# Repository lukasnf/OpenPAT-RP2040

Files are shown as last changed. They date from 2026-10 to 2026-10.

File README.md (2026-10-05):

# OpenPAT-RP2040

> **⚠️ SAFETY DISCLAIMER:** This project is for educational and preliminary diagnostic purposes only. While it tests electrical safety parameters, it is **not** a certified Portable Appliance Tester (PAT). It does not replace legally required safety tests conducted with calibrated and certified equipment. Always assume appliances are dangerous until proven otherwise.

**OpenPAT-RP2040** is a low-voltage Portable Appliance Tester based on the RP2040 microcontroller. It is designed to safely measure Protective Earth (PE) continuity at standard test currents (200mA) and verify Phase-to-Neutral (L-N) resistance on **unpowered** appliances. 

Operating completely without high measurement voltages, this design allows for safe preliminary testing of appliances. 

> **Note:** This project is currently under active development. The schematics and PCB layout have been designed using KiCad and manufactured via JLCPCB.

---

## 🛠 Hardware Architecture

The measurement circuitry is designed around the RP2040 and relies on a dedicated analog frontend for precise, low-voltage readings. Based on the schematic, the core components and sub-circuits include:

* **Microcontroller:** RP2040
* **Analog-to-Digital Converter (ADC):** ADS1115 connected via I2C (`I2C_SCL`, `I2C_SDA`) to read the measurement nodes (`PE_TEST`, `PE_TEST_RE`, `L_T`, `N_T`).
* **PE Test Current Source:** A constant current source generating approximately 200mA. This is achieved using an LM317 linear regulator (U1) combined with a 6.2Ω / 1W resistor (R1).
* **PE Continuity Measurement:** Employs a **4-wire (Kelvin) measurement method** to accurately determine resistance by eliminating the voltage drop across the test leads. This is implemented using separate connections for force (`PE_FORCE_IN`, `PE_OUT1`) and sense (`PE_SENSE_1`, which connects to the protected `PE_TEST_RE` node).
* **L-N Resistance Measurement:** Controlled via RP2040 GPIOs. An NMOS transistor (Q1, controlled by GP26) and a switched pull-up (via GP27 and a 1kΩ resistor) are used to configure the circuit to measure the resistance between the Phase and Neutral test points via the L/N_TEST1 connector.
* **Input Protection:** All sensitive analog measurement lines are protected against transients. The circuit uses 10kΩ series resistors (R2, R3, R4, R5) and BAT54S dual Schottky diodes (D1, D2, D3, D4) to safely clamp the ADC inputs to the 3.3V rail and Ground.

## 📂 Repository Contents
Bildschirmfoto 2026-10-05 um 15 35 09



...

## 📄 License

This repository contains both hardware design files and software source code, which are licensed differently:

* **Hardware:** All hardware design files (schematics, PCB layouts) are released under the [CERN Open Hardware Licence Version 2 - Strongly Reciprocal (CERN-OHL-S v2)](LICENSE).
* **Software:** All source code is released under the [MIT License](LICENSE-MIT).

This README was drafted with AI assistance. All technical information has been manually verified by the author.

Lukas F.

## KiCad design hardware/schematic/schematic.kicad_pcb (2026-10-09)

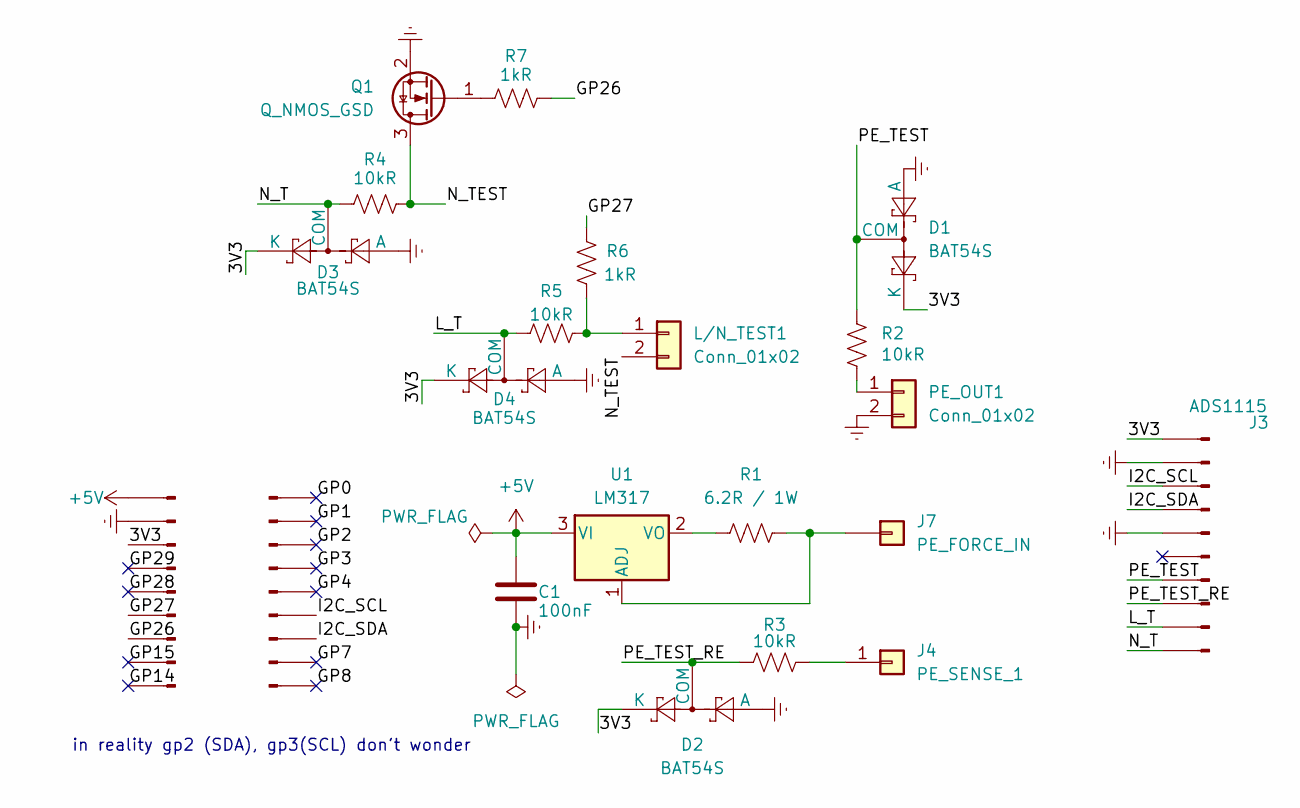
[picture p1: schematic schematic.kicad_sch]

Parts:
C1: 100nF; C_Disc_D5.0mm_W2.5mm_P2.50mm
D1, D2, D3, D4: BAT54S; SOT-23
J1, J2: Conn_01x09_Pin; PinHeader_1x09_P2.54mm_Vertical
J3: ADS1115; PinHeader_1x10_P2.54mm_Vertical
J4: PE_SENSE_1; PinHeader_1x01_P2.54mm_Vertical
J7: PE_FORCE_IN; PinHeader_1x01_P2.54mm_Vertical
L/N_TEST1: Conn_01x02; TerminalBlock_Phoenix_MKDS-1,5-2-5.08_1x02_P5.08mm_Horizont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
PE_OUT1: Conn_01x02; TerminalBlock_Phoenix_MKDS-1,5-2-5.08_1x02_P5.08mm_Horizont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
Q1: Q_NMOS_GSD; SOT-23
R1: 6.2R / 1W; R_Axial_DIN0411_L9.9mm_D3.6mm_P12.70mm_Horizontal
R2, R3, R4, R5: 10kR; R_Axial_DIN0207_L6.3mm_D2.5mm_P10.16mm_Horizontal
R6, R7: 1kR; R_Axial_DIN0207_L6.3mm_D2.5mm_P10.16mm_Horizontal
U1: LM317; TO-220-3_Vertical

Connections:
+5V: C1.1, J2.9, U1.3 (VI)
/3V3: D1.2 (K), D2.2 (K), D3.2 (K), D4.2 (K), J2.7, J3.10
/GP0: J1.1
/GP1: J1.2
/GP2: J1.3
/GP3: J1.4
/GP4: J1.5
/GP7: J1.8
/GP8: J1.9
/GP14: J2.1
/GP15: J2.2
/GP26: J2.3, R7.2
/GP27: J2.4, R6.1
/GP28: J2.5
/GP29: J2.6
/I2C_SCL: J1.6, J3.8
/I2C_SDA: J1.7, J3.7
/L_T: D4.3 (COM), J3.2, R5.1
/N_T: D3.3 (COM), J3.1, R4.1
/N_TEST: L/N_TEST1.2, Q1.3 (D), R4.2
/PE_TEST: D1.3 (COM), J3.4, R2.1
/PE_TEST_RE: D2.3 (COM), J3.3, R3.2
GNDREF: C1.2, D1.1 (A), D2.1 (A), D3.1 (A), D4.1 (A), J2.8, J3.6, J3.9, PE_OUT1.2, Q1.2 (S)
unnamed: J4.1 (Pin_1_1), R3.1
unnamed: J7.1 (Pin_1_1), R1.2, U1.1 (ADJ)
unnamed: L/N_TEST1.1, R5.2, R6.2
unnamed: PE_OUT1.1, R2.2
unnamed: Q1.1 (G), R7.1
unnamed: R1.1, U1.2 (VO)

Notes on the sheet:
in reality gp2 (SDA), gp3(SCL) don't wonder

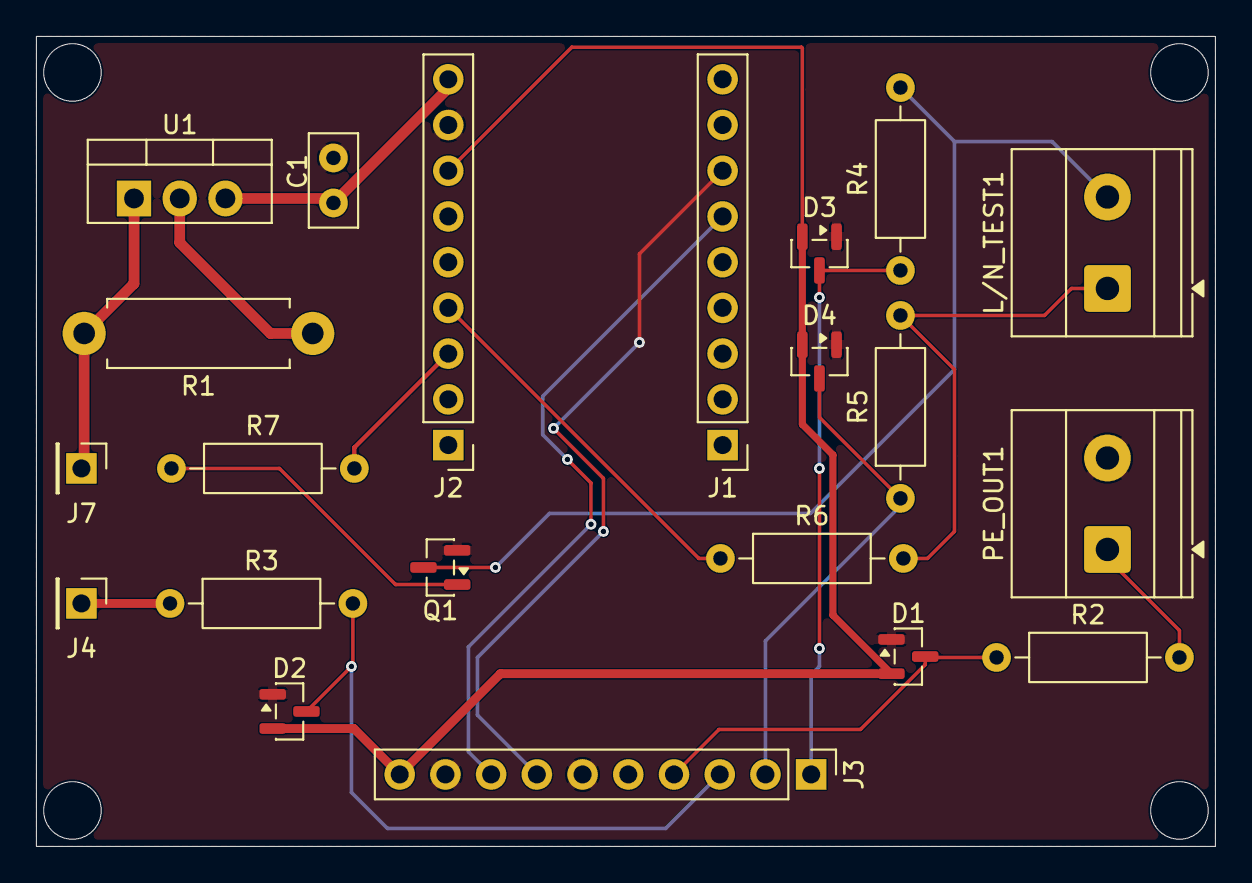
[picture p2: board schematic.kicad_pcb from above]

Board: 2 copper layers, 65.5 x 45.0 mm, 21 parts (0 on the bottom side), 18 nets.

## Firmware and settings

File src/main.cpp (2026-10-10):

#include <Arduino.h>
#include <Wire.h>
#include <Adafruit_ADS1X15.h>

Adafruit_ADS1115 ads; 

// pin definitions
const int MOSFET_GATE = 26; // GPIO 26 for MOSFET gate
const int L_DRIVE = 27; // GPIO 27 for L drive

// ADS pins definitions
const int ADS_PE_HIGH = 0; // PE_TEST_RE
const int ADS_PE_LOW  = 1; // PE_TEST
const int ADS_L_T     = 2; // L_T
const int ADS_N_T     = 3; // N_T

// constants
const float PE_CURRENT_A = 0.2016; // current in Amperes for PE TEST
const float R6 = 990.0; // R6 resistance in Ohms
const float RP2040_VCC = 3.224; // output voltage of the RP2040 (3.3V)

void measurePE();
void measureLN();
void setup() {
  Serial.begin(115200);
  
  while (!Serial) {
    delay(10);
  }
  
  delay(2000); 
  Serial.println("\n--- BOOTING OpenPAT-RP2040 ---");

  pinMode(MOSFET_GATE, OUTPUT);
  pinMode(L_DRIVE, OUTPUT);
  digitalWrite(MOSFET_GATE, LOW);
  digitalWrite(L_DRIVE, LOW);

  Wire1.setSDA(2); 
  Wire1.setSCL(3); 
  Wire1.begin();
  
  Serial.println("I2C1 booted");

  if (!ads.begin(0x48, &Wire1)) {
    while (1) {
      Serial.println("Error: ADS1115 not found!");
      delay(1000);
    }
  }

  ads.setGain(GAIN_ONE);
  Serial.println("System ready. Press 'p' for PE-Test, 'l' for L/N-Test");
}

void loop() {
  if (Serial.available() > 0) {
    char input = Serial.read();
    
    if (input == 'P' || input == 'p') {
      measurePE();
    } 
    else if (input == 'L' || input == 'l') {
      measureLN();
    }
    else if (input == 'Q' || input == 'q') {
      digitalWrite(L_DRIVE, LOW);
      digitalWrite(MOSFET_GATE, LOW);
      Serial.println("\n Standby.");
    }
  }
}

void measurePE() {
  Serial.println("\n Starting PE-Test...");

   // differential measurement between ADS_PE_TEST and ADS_PE_TEST_RE
  int16_t adc0_1 = ads.readADC_Differential_0_1();
  
  // calculate the voltage (1 Bit = .125 mV)
  float voltage_PE = (adc0_1 * 0.125) / 1000.0;

  // calculating the resistance of PE
  float resistance_PE = voltage_PE / PE_CURRENT_A;

  // output the results
  Serial.print("Voltaged Drop: "); Serial.print(voltage_PE, 4); Serial.println(" V");
  Serial.print("PE Resistance:   "); Serial.print(resistance_PE, 3); Serial.println(" Ohm");
}


void measureLN() {
  Serial.println("\n Starting L/N-Test...");

  // turn on Mosfet
  digitalWrite(MOSFET_GATE, HIGH);

  // apply voltage to L (via R6)
  digitalWrite(L_DRIVE, HIGH);
  delay(10);

  // measure voltage across L_T and N_T
  int16_t adcL = ads.readADC_SingleEnded(ADS_L_T);
  int16_t adcN = ads.readADC_SingleEnded(ADS_N_T);

  // convert raw ADC values to Volts
  float v_L = (adcL * 0.125) / 1000.0;
  float v_N = (adcN * 0.125) / 1000.0;

  // calculate voltage drop across the DUT
  float voltage_DUT = v_L - v_N;

  // calculate the current through the DUT 
  float current_DUT = (RP2040_VCC - v_L) / R6;

  // calculate the resistance of the DUT
  float resistance_LN = -1; // -1 as default value
  if (current_DUT > 0.0001) { // Prevent division by zero if no load is connected
    resistance_LN = voltage_DUT / current_DUT;
  }

  // Turn everything off 
  digitalWrite(L_DRIVE, LOW);
  digitalWrite(MOSFET_GATE, LOW);

  // output the results
  Serial.print("Voltage at L_T: "); Serial.print(v_L, 3); Serial.println(" V");
  Serial.print("Voltage at N_T: "); Serial.print(v_N, 3); Serial.println(" V");
  
  if (resistance_LN >= 0) {
    Serial.print("L/N Resistance: "); Serial.print(resistance_LN, 1); Serial.println(" Ohm");
  } else {
    Serial.println("L/N Resistance: No continuity");
  }
}

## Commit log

2026-09-07 init hardware folder
    [schematic.kicad_pcb, schematic.kicad_sch]
2026-09-09 schemativ v1.0
    [schematic.kicad_sch]
2026-09-10 finished schematic
    [schematic.kicad_pcb, schematic.kicad_sch]
2026-09-15 finished v01 pcb
    [schematic.kicad_pcb, schematic.kicad_sch]
2026-10-05 Refactor measurement circuitry section in README
    Removed citations and formatted the ADC, PE Test Current Source, PE Continuity Measurement, L-N Resistance Measurement, and Input Protection sections for clarity.
2026-10-05 Update hardware architecture description in README
    Removed unnecessary reference to the schematic image in the hardware architecture section.
2026-10-09 fixed schematic issue
    [schematic.kicad_pcb, schematic.kicad_sch]
